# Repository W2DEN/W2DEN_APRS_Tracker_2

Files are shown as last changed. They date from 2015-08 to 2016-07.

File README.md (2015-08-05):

# W2DEN_APRS_Tracker_2
Tracker with a menu
This version will include a menu to allow users to change some of the 'default' data. A new version 'thread' was created so the original Tracker did not change. this will allow other development without the menu system included.
Who knows, where this is going!
UPDATE 8/5/15: For all practical purposes the software is complete. There will be some code refinements, the menu system is 'brute force' coding and needs some sophisitcation.
Documentaion will be brought up to speed on the N4SER.org site. 
NOTE: libraries included with the Arduino IDE and/or the Tensyduino IDE are NOT captured here. They will be documented as time allows.
73
Den

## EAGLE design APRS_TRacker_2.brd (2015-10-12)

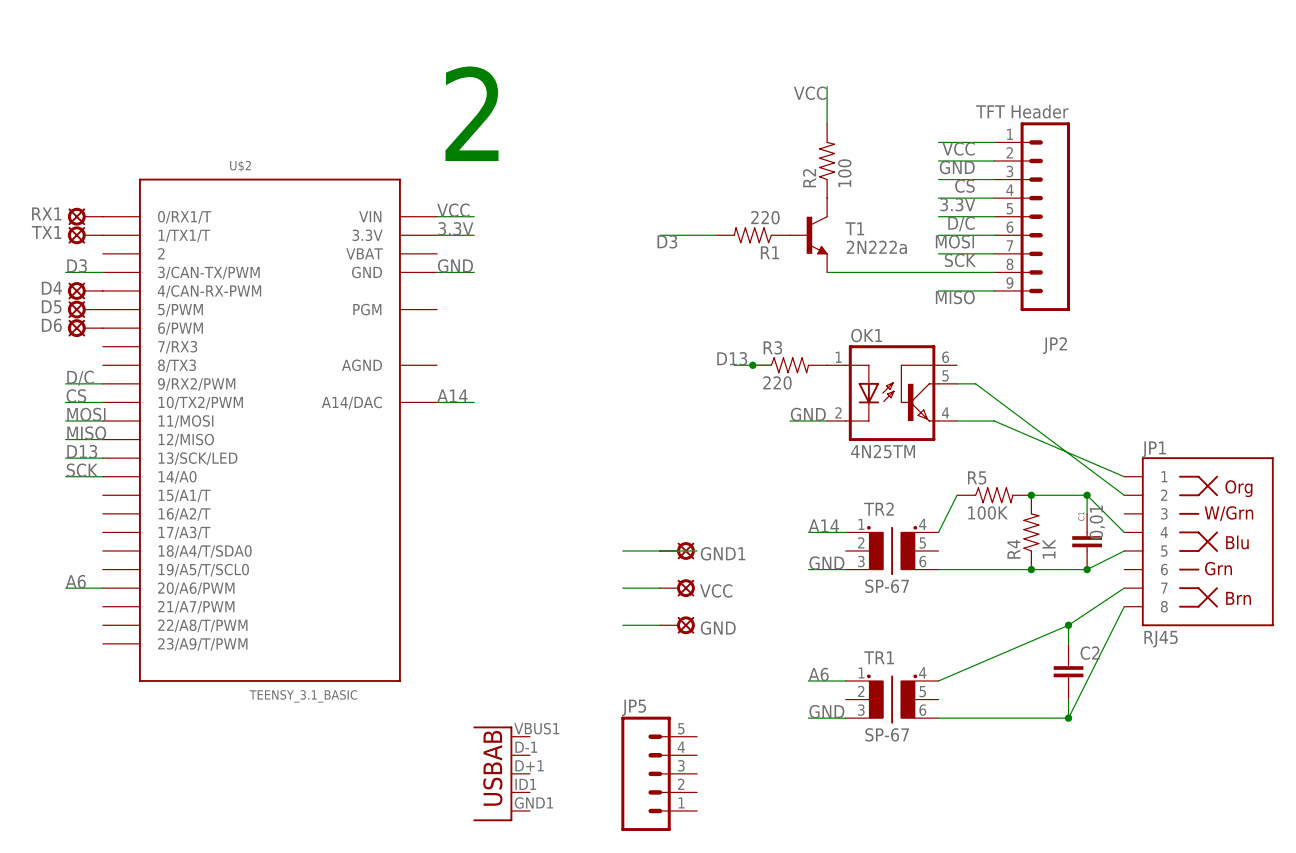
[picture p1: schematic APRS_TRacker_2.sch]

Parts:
C1: 0,01; CAP-PTH-SMALL2
C2: CAPPTH2; CAP-PTH-SMALL2
D4, D5, D6: LSP10
GND, GND1: LSP10
JP1: RJ45; RJ45-8
JP2: TFT Header; 1X09
JP5: M05PTH; 1X05
OK1: 4N25TM; DIL6-04
R1, R3: 220; AXIAL-0.4
R2: 100; AXIAL-0.4
R4: 1K; AXIAL-0.4
R5: 100K; AXIAL-0.4
RX1: LSP10
T1: 2N222a; TO-92
TR1, TR2: SP-67
TX1: LSP10
U$2: TEENSY_3.1_BASIC
U$4: USB-AB""; USB-AB-MICRO-SMD_V02_BOSS
VCC: LSP10

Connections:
3.3V: JP2.4, U$2.3.3V, U$2.3.3V1 (3.3V)
A6: TR1.1, U$2.20/A6 (20/A6/PWM)
A14: TR2.1, U$2.A14 (A14/DAC)
AGND: U$2.AGND
CS: JP2.3, U$2.10 (10/TX2/PWM)
D3: R1.P$2 (2), U$2.3 (3/CAN-TX/PWM)
D13: R3.P$1 (1), U$2.13 (13/SCK/LED)
D/C: JP2.5, U$2.9 (9/RX2/PWM)
GND: GND.MP, GND1.MP, JP2.2, OK1.2 (C), TR1.3, TR2.3, U$2.GND, U$2.GND1 (GND)
MISO: JP2.9, U$2.12 (12/MISO)
MOSI: JP2.6, U$2.11 (11/MOSI)
unnamed: R1.P$1 (1), T1.2 (B)
unnamed: R2.P$1 (1), T1.1 (C)
unnamed: OK1.1 (A), R3.P$2 (2)
unnamed: JP1.1, OK1.4 (EMI)
unnamed: JP1.2, OK1.5 (COL)
unnamed: C2.2, JP1.8, TR1.6
unnamed: C2.1, JP1.7, TR1.4
unnamed: C1.1, JP1.4, R4.P$2 (2), R5.P$2 (2)
unnamed: C1.2, JP1.5, R4.P$1 (1), TR2.6
unnamed: R5.P$1 (1), TR2.4
unnamed: D5.MP, U$2.5 (5/PWM)
unnamed: D6.MP, U$2.6 (6/PWM)
unnamed: D4.MP, U$2.4 (4/CAN-RX-PWM)
unnamed: RX1.MP, U$2.0 (0/RX1/T)
unnamed: TX1.MP, U$2.1 (1/TX1/T)
SCK: JP2.7, U$2.14/A0
T1: JP2.8, T1.3 (E)
VBAT: U$2.VBAT
VCC: JP2.1, R2.P$2 (2), U$2.VIN, VCC.MP

Board: 2 copper layers, 24 parts (1 on the bottom side), 28 nets, no tracks yet.

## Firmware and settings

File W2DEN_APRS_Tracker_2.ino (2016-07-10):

/*
* This is W2DEN's attempt at a Teensy3.1 APRS Tracker.
* This is V 2.03 adding a menu system to allow user input.
* see N4SER.org for details
* 
* Debugging: 
*   All serial.print lines have been remed out. //Serial.print. Un rem to use
*   Incuding the initiator line in Setup //Serial.begin(9600);
*
* Compiler Macro Substitutes (#define) in ALL_CAPS with underline for spaces
*
* The bases for this sketch comes from Richard Nash (KC3ARY). Without his code I'd still be searching
* Also thanks to:
*
    Ben Buxton: rotary encoder code ( http://www.buxtronix.net/2011/10/rotary-encoders-done-properly.html )
    9W2SVT: ASPRS Arduino with Display ( http://9w2svt.blogspot.com/ )
    M1GEO: APRS Blog ( http://www.george-smart.co.uk/wiki/APRS )
    KI4MCW: Balloonery ( https://sites.google.com/site/ki4mcw/ )
    BeRTOS Project ...
    Jinseok Jeon (JeonLab.wordpress.com): UTC calculator
    The APRS libraries come from the Trackduino project with modes by many before it got here.
Special mention goe to Jan Volschenk (ZS6VOL) who actuall built a W2DEN Tracker and helped me debug this code.
*
********************************************************************
*
*/
#define thisver "2.03" ////////////////////////////////// VERSION
// these define the starting EEPROM addresses.
// easier to change these than dig for the constants.
#define UTC_OFFSET 1
#define XMIT_TIME  2
#define MY_CALL    4
#define MY_SSID   10
#define DEST_CALL 11
#define DEST_SSID 17
#define SYM_TABLE 18
#define SYMBOL    19
#define COMMENT   20
#define SB_ENABLE    55 // these are SmartBeaconing eePROM addresses
#define SBFAST_SPEED 56
#define SBFAST_RATE  58
#define SBSLOW_SPEED 60
#define SBSLOW_RATE  62
#define SBTURN_TIME  64
#define SBTURN_ANGLE 66
#define SBTURN_SLOPE 68
#define AXDELAY      70
#define AXFLAGS      72
#define AXVOXON      74
#define AXVOXSILENT  76
#define PTT_PIN      78
#define TFT_ONOFF    80 // tft On / Off (1 / 0) EEPROM address only 1 byte
#define SQUELCH      81 // the squelch threshol eeprom address 

#define COMMLENGTH  35 // length of the AX.25 comment
#define NUM_SYMBOLS 10 // number of symbols in the symbols[] table

// includes
#include <WProgram.h>
#include <GPS.h>
#include <aprs.h>
#include <EEPROMex.h> // expanded EEPROM library

#include "SPI.h" // Set up the display
#include "ILI9341_t3.h"
ILI9341_t3 tft = ILI9341_t3(10, 9, 8, 11, 14, 12); //(CS,DC,RST,MOSI,SCLK,MISC)

static const int line = 25; //# of lines on screen @ font size 3

// rotary selector
#include <Bounce.h>
#define ROTARY_PIN1 5
#define ROTARY_PIN2 6
#define BUTTONPIN   4
#define DIR_CCW 0x10
#define DIR_CW 0x20
Bounce pushbutton = Bounce(BUTTONPIN, 10);
// Use the full-step state table (emits a code at 00 only)
const unsigned char ttable[7][4] = {
  {0x0, 0x2, 0x4,  0x0}, {0x3, 0x0, 0x1, 0x10},
  {0x3, 0x2, 0x0,  0x0}, {0x3, 0x2, 0x1,  0x0},
  {0x6, 0x0, 0x4,  0x0}, {0x6, 0x5, 0x0, 0x20},
  {0x6, 0x5, 0x4,  0x0},
};
volatile unsigned char state = 0;
void rotary_init() { // setas up the rotatry pins
  pinMode(ROTARY_PIN1, INPUT_PULLUP);
  pinMode(ROTARY_PIN2, INPUT_PULLUP);
  pinMode(BUTTONPIN, INPUT_PULLUP);
}
/* Read input pins and process for events. Call this either from a
 * loop or an interrupt (eg pin change or timer).
 * Returns 0 on no event, otherwise 0x80 or 0x40 depending on the direction.
 */
unsigned char rotary_process() {
  unsigned char pinstate = (digitalRead(ROTARY_PIN2) << 1) | digitalRead(ROTARY_PIN1);
  state = ttable[state & 0xf][pinstate];
  return (state & 0x30);
}
int DaysAMonth[] = { 31, 28, 31, 30, 31, 30, 31, 31, 30, 31, 30, 31};//number of days a month
int gpsYear;
int gpsMonth;
int gpsDay = 0;
int gpsHour;
#define knotToMPH 1.15078 // GPS speed is in knots... this is the conversion
////////////////////////////////////////////////////////////////////////////////

// Define the I/O pins
//#define PTT_PIN 13 // Push to talk pin tis is now eePROM
#define ROTARY_PIN1   5
#define ROTARY_PIN2   6
#define BUTTONPIN     4
#define TFT_ONOFF_PIN 3 // tft On Off PWM pin
#define SQUEL_PIN     A6       // these are constants for the squelch threshold
#define SQUEL_REF     INTERNAL
#define SQUEL_RES     10
#define SQUEL_AVE     16

////////////// user data set up //////////////////////////////
//
//this is all new. User data are read from EEPROM
//
// create the struct instance for the calls and paths//////////
//
struct PathAddress addresses[] = {
  {(char *)NULL, 0},  // Destination callsign
  {(char *)NULL, 0},  // Source callsign
  {(char *)NULL, 0},  // Digi1 (first digi in the chain)
  {(char *)NULL, 0}   // Digi2 (second digi in the chain)
};
//
// set up variables to hold EEPROM data //////////////////////
// make these global so we can edit them.
// variables are loaded to each xmit
//
int8_t TimeZone;    // utc offseti
uint16_t sTime;      // xmit delay if no smart beacon
char sCall[6];      // holds the s source call
char dCall[6];      // holds the d destination call
char buf;           // buffer for EEPROM read
char symTable;      // symbole table \ or //
char symbol;        // symbol > car etc/
char myComment[36]; // comments holder 35 chars + end
const char* symbols [][9] = { //table of symbols
  {"House", "/", "/"},
  {"Car", "/", ">"},
  {"M-Cycle", "/", "<"},
  {"Van", "/", "v"},
  {"Truck", "/", "k"},
  {"Bike", "/", "b"},
  {"Balloon", "/", "O"},
  {"SailBoat", "/", "y"},
  {"PwrBoat", "/", "s"},
  {"School", "/", "K"}
};
int8_t   sbEnable;       // use sb or not
uint16_t sbFastSpeed;    //mph speeds stored and compared as integers tostop oscilatting
uint16_t sbFastRate;     //seconds
uint16_t sbSlowSpeed;    // mph as integer
uint16_t sbSlowRate;
uint16_t sbMinTurnTime;  //sec
uint16_t sbMinTurnAngle; //degrees
uint16_t sbTurnSlope;    //
uint16_t axDelay;        // milliseconds
uint16_t axFlags;        // number of flags to send
uint16_t axVoxOn;        // mseconds vox tone sent to xmitter 0 for off
uint16_t axVoxSilent;    // mseconds VOX tone silent  0 for off
uint16_t pttPin;         // PTT Teensy Pin usually 13, 0 for off
int8_t   tftOnOff;       // tft brightness setting
uint16_t squelch;        // squelch threshold vlaue holder

uint16_t mySpeed   = 0;  // Holds gps.speed for processing
uint16_t myHeading = 0;
uint16_t sbSpeed   = 0;  //prior read speed
uint16_t sbHeading = 0;  // prior heading
//////////////////////// pre set up variables///////////////////////////
HardwareSerial &gpsSerial = Serial1;
GPS gps(&gpsSerial, true);
void mNumChoice(int eePromAddress, int8_t *variable, int lTZ, int uTZ,  int nTZ, String title, String help , uint16_t TTT = 0, uint16_t *variable2 = 0, bool e16bit = false );

uint32_t dTime;
uint32_t timeOfAPRS = 0;
bool gotGPS = false;

////////////////////////////////////////////////////////////////////////
////////////////////////////////////////////////////////// setup()
////////////////////////////////////////////////////////////////////////
void setup()
{
  //Serial.begin(9600); // For debugging output over the USB port
  // read the EEPROM user data into memory /// will be updated/////////
  /////////////////////////////////////////////////////////////////////
  TimeZone = EEPROM.read(UTC_OFFSET);
  // sTime is the start delay time sotred in eePROM as an int in seconds
  // dTime is the working xmit delay uint32_t starts as sTime then via SmartBeacon if activated.
  sTime = EEPROM.readInt(XMIT_TIME); // seconds
  dTime = sTime * 1000; // store the start time into dTime (delay) in milliseconds
  for (int i = MY_CALL; i < MY_CALL + 6; i++) { // Source call
    buf = EEPROM.read(i);
    if (buf == 32) break;
    sCall[i - MY_CALL] = buf;
  }
  for (int i = DEST_CALL; i < DEST_CALL + 6; i++) { //destinationn call
    buf = EEPROM.read(i);
    if (buf == 32) break;
    dCall[i - DEST_CALL] = buf;
  }

  for (int i = COMMENT; i < COMMENT + COMMLENGTH; i++) { // comment
    buf = EEPROM.read(i);
    myComment[i - COMMENT] = buf;
  }
  // now the SmartBeacon parameters...
  // 16 bit allows menu compatability
  sbEnable       = EEPROM.read(SB_ENABLE);
  sbFastSpeed    = EEPROM.readInt(SBFAST_SPEED); //mph speeds stored and compared as integers tostop oscilatting
  sbFastRate     = EEPROM.readInt(SBFAST_RATE);  //seconds
  sbSlowSpeed    = EEPROM.readInt(SBSLOW_SPEED); // mph as integer
  sbSlowRate     = EEPROM.readInt(SBSLOW_RATE);
  sbMinTurnTime  = EEPROM.readInt(SBTURN_TIME);  // sec
  sbMinTurnAngle = EEPROM.readInt(SBTURN_ANGLE); // degrees
  sbTurnSlope    = EEPROM.readInt(SBTURN_SLOPE); //
  axDelay        = EEPROM.readInt(AXDELAY);      // milliseconds
  axFlags        = EEPROM.readInt(AXFLAGS);      // number of flags to send
  axVoxOn        = EEPROM.readInt(AXVOXON );     // mseconds vox tone sent to xmitter 0 for off
  axVoxSilent    = EEPROM.readInt(AXVOXSILENT);  // mseconds VOX tone silent  0 for off
  pttPin         = EEPROM.readInt(PTT_PIN);      // PTT Teensy Pin usually 13, 0 for off
  tftOnOff       = EEPROM.read(TFT_ONOFF);       // tft On / Off: 1 or 0
  squelch        = EEPROM.readInt(SQUELCH);      // read ssquelch threshold from eePROM into variable
  /////////////////////////////////////////////////////////////////////////////////////////////////////
  tft.begin();
  pinMode(TFT_ONOFF_PIN, OUTPUT);
  digitalWrite(TFT_ONOFF_PIN, 1); /// this is the TFT display On Off set to on for boot
  tft.fillScreen(ILI9341_BLACK);
  tft.setRotation(2);
  tft.setCursor(0, 250);
  tft.setTextSize(2);
  if (tftOnOff) {
    tft.print("Display: On");
  }
  else {
    tft.print("Display: Off");
  }
  tft.setTextSize(3);
  tft.setTextColor(ILI9341_YELLOW, ILI9341_BLACK);
  tft.setCursor(0, 50);
  tft.println("W2DEN's");
  tft.println("APRS");
  tft.println("Tracker");
  tft.println("Loading ...");

  // start the GPS polling and wait for valid data... may take 15+ seconds
  gps.startSerial(9600);
  gps.setSentencesToReceive(OUTPUT_RMC_GGA);
  rotary_init(); // initialize the rotary
  // wait for a GPS sentence
  while (!(gps.sentenceAvailable())) {
    delay(1000);
  }

  gps.parseSentence();
  gps.dataRead();
  //   only proced if the dates are valid
  char rot[9] = {'|', '/', (char)195, '\\', '|', '/', (char)195, '\\'};
  uint i = 0;
  while (gps.month <= 0 || gps.day <= 0 || gps.year <= 0) { // || gps.speed > 0) {
    //Serial.print( gps.month);
    //Serial.print( "/");
    //Serial.print( gps.day);
    //Serial.print( "/");
    //Serial.println( gps.year);
    if (gps.sentenceAvailable()) gps.parseSentence();
    if (gps.newValuesSinceDataRead()) gps.dataRead();
    tft.setCursor(0, 150);
    tft.print(rot[i++]);
    if (i >= sizeof(rot) - 1) i = 0;
    delay(1000);
  }
  // Set up the APRS module
  aprs_setup(axFlags, // number of preamble flags (FLAG) (Hex: 0x7e, ASCII: ~, Binary: 01111110 )to send
             pttPin, // PTT Pin from eePROM
             axDelay, // ms to wait after PTT to transmit
             axVoxOn, axVoxSilent // VOX: tone length, silence length
            );

  // now data should be stable. Get set and enter the loop
  sbSpeed   = gps.speed;                //prior read speed
  sbHeading = gps.heading;
  myHeading = sbHeading;
  broadcastLocation(gps, myComment);
  timeOfAPRS = millis();
  digitalWrite(TFT_ONOFF_PIN, tftOnOff); /// this is the TFT display controller set to 255 on boot
  tft.fillScreen(ILI9341_BLACK);
  display();
  //eepromReader(); // for debugging: prints eeprom content t serial monitor 
  //Serial.printf("mPick: %i, mB4: %i\n\r", " mPick", " mB4");

}

////////////////////////////////////////////////////////////////////// loop()
void loop()
{
  // capture the button press
  if (pushbutton.update()) {
    //Serial.println("Button");
    if (pushbutton.fallingEdge()) {
      digitalWrite(TFT_ONOFF_PIN, 1); //Turn the screen on if it was off
      menu(addresses);
    }
  }

  // get GPS data
  if (gps.sentenceAvailable()) gps.parseSentence();
  if (gps.newValuesSinceDataRead()) {         // go here as the seconds tick
    displayCountDown();
    gps.dataRead();
    gotGPS = true; // prior validate idea... on the to do list
    if (sbEnable) {
      mySpeed   = round(gps.speed * knotToMPH); // convert knots to MPH and store.
      myHeading = round(gps.heading);           // store the heading
      // SmartBeacon... my way
      if ((sbSpeed != mySpeed)) {               // was speed changed?????
        //go if something changed
        if ((mySpeed > sbSlowSpeed) && (mySpeed < sbFastSpeed)) {
          dTime = (( ( float(sbFastSpeed) / float(mySpeed) ) * (sbFastRate)) * 1000); // - (millis() - timeOfAPRS);
        }
        if (mySpeed >= sbFastSpeed) {         // are we above the fast level
          dTime = (sbFastRate * 1000);        // - (millis() - timeOfAPRS);
        }
      }
      if (sbHeading != myHeading) {             // was heading changed?????????
        uint16_t sbTurnThreshold = sbMinTurnAngle + (sbTurnSlope / mySpeed); // smartbeacon formula
        //  do we send beacon for a direction change??
        int dif = sbHeading - myHeading;
        dif = abs(dif);
        if (abs(dif) > 180) {
          dif = dif - 360;
        }
        dif = abs(dif);
        if (dif > sbTurnThreshold) {                              //did we trun enough?
          if (((millis() - timeOfAPRS) / 1000) > sbMinTurnTime) { //did enough time pass?
            timeOfAPRS = millis() - dTime;        // set the tme so we xmit
            sbHeading = myHeading;
          }
          else {
            //Serial.println("not enuf time... reset");
            sbHeading = myHeading;              //not enough time so reset the heading and move on
          }
        }
      }
    }
    display();
    //Serial.printf("Sec: %d Heading %d Knots: %f\n\r", gps.seconds, gps.heading, gps.speed);
    //Serial.printf("Location: %f, %f Heading %d Knots: %f\n\r", gps.latitude, gps.longitude,gps.heading, gps.speed);
    //Serial.printf("dTime %i timeOf %i dT+timeOf %i millis %i\n\r", dTime, timeOfAPRS, dTime + timeOfAPRS, millis());
    //Serial.print((millis() - timeOfAPRS) / 1000);
  }
  // do we xmit?
  if (gotGPS && timeOfAPRS + dTime < millis()) {
    broadcastLocation(gps, myComment );
    timeOfAPRS = millis(); // reset the timer
    //Serial.printf("dTime: %d gps.speed: %f sbSpeed %f sbSlowrate: %d\n\r", dTime, gps.speed, sbSpeed , sbSlowRate);
    // SmartBeacon speed < low speed test and adjust as needed.
    if (sbEnable) {
      sbHeading = gps.heading; // reset the heading milestone.
      sbSpeed = gps.speed * knotToMPH; //store the new speed.
      if (gps.speed < sbSlowSpeed && sbSpeed < sbSlowSpeed && dTime < (sbSlowRate * 1000) ) {
        dTime = 2 * dTime;
        if (dTime > (sbSlowRate * 1000) ) dTime = sbSlowRate * 1000;
      }
    }
    display();
  }
} // Loop end YES the main loop ends here...


/////////////////////////////////////////////////////////////////////////////
//                                                                         //
//       FUNCTIONS from here down                                          //
//                                                                         //
/////////////////////////////////////////////////////////////////////////////

////////////////////////////////////////////////////////////// eepromReader()
// for debugging prints eeprom content to serial monitor
void eepromReader() {
  unsigned int address = 0;
  byte value;
  Serial.print("EEPROM Content");
  Serial.println();
  while (address < 100) {
    // read a byte from the current address of the EEPROM
    value = EEPROM.read(address);

    Serial.print(address);
    Serial.print("\t");
    Serial.print(value, DEC);
    if (value > 30 and value < 240) {
      Serial.print("\t");
      Serial.print(char(value));
    }
    Serial.println();
    address = address + 1;
  }
}

/////////////////////////////////////////////////////////////////////// squelcher()
// returns the integer value on the SQUEL_PIN
int squelcher() {
  // read the audio level 10 times at 10 millisecond inetervals (100 msec )
  // return the total
  analogReference(SQUEL_REF );
  analogReadResolution(SQUEL_RES);
  analogReadAveraging(SQUEL_AVE);
  int t = 0;
  for (int i = 0; i < 10; i++) {
    t = t + analogRead(SQUEL_PIN);
    delay (10);
  }
  return t;
}


/////////////////////////////////////////////////////////////////////// menuHeader()
// draws the menus
//
void menuHeader(String title, int mStart, int mEnd, int mPick, String menu1[][2]  ) {
  tft.fillScreen(ILI9341_BLUE);
  tft.setTextSize(3);
  tft.setTextColor(ILI9341_WHITE, ILI9341_BLUE);
  tft.setCursor(0, 0);
  tft.println(title);
  for (int i = mStart; i <= mEnd; i++) {
    tft.setCursor(0, (i + 1) * 25);
    if (i == mPick) {
      tft.setTextColor(ILI9341_BLUE, ILI9341_WHITE);
    }
    else
    {
      tft.setTextColor(ILI9341_WHITE, ILI9341_BLUE);
    }
    //tft.print(String(i) + " ");
    tft.print(menu1[i][0] + menu1[i][1]);
  }
}


/////////////////////////////////////////////////////////////////////// menu()
void menu(const PathAddress *  paths) {
  {
    // lets set it up
    int mStart = 0;   //First menu item
    int mEnd   = 5;   // last menu item
    int mPick  = 0;   // menu choice
    int mB4    = 0;   // line # befor move
    String onOff;
    if (tftOnOff) {
      onOff = "On";
    }
    else {
      onOff = "Off";
    }
    //String displayOnOff = "Display:" + onOff;
    //this defines the menu
    String menu1[][2] = {
      {"Return", ""},
      {"Send/Return", ""},
      {"Packet", ""},
      {"AX.25", ""},
      {"SmartBeacon", ""},
      {"Display: " , onOff}
    } ;
    //now draw it
    menuHeader("Main  Menu", mStart, mEnd, mPick, menu1  );
    // now loop looking for a rotation or a button press
    while (true)
    {
      unsigned char result = rotary_process(); // rotated?
      if (result) {                            // the button was rotated
        if (result == DIR_CCW) {               // highlight the next choice
          if (--mPick < mStart) mPick = mEnd;
        }
        else {
          if (++mPick > mEnd) mPick = mStart;
        }
        Serial.printf("mPick: %i, mB4: %i\n\r", mPick, mB4);
        tft.setCursor(0, (mB4 + 1) * 25);
        tft.setTextColor(ILI9341_WHITE, ILI9341_BLUE);
        tft.print(menu1[mB4][0] + menu1[mB4][1]);
        tft.setCursor(0, (mPick + 1) * 25);
        tft.setTextColor(ILI9341_BLUE, ILI9341_WHITE);
        tft.print(menu1[mPick][0] + menu1[mPick][1]);
        tft.setTextColor(ILI9341_WHITE, ILI9341_BLUE);
        mB4 = mPick;
      }
      if (pushbutton.update()) {                // button pushed
        if (pushbutton.fallingEdge()) {
          switch (mPick) {                      //handle the button push
            case 0:  // return
              tft.fillScreen(ILI9341_BLACK);
              display();
              digitalWrite(TFT_ONOFF_PIN, tftOnOff); // reset the display
              return;
            case 1:  // send and return
              gps.dataRead();
              broadcastLocation(gps, myComment );
              tft.fillScreen(ILI9341_BLACK);
              timeOfAPRS = millis();
              display();
              digitalWrite(TFT_ONOFF_PIN, tftOnOff); // reset the display
              return;
            case 2: // sendMenu
              packetMenu(paths);
              menuHeader("Main  Menu", mStart, mEnd, 2, menu1  );
              break;
            case 3: // sendMenu
              ax25Menu();
              menuHeader("Main  Menu", mStart, mEnd, 3, menu1  );
              break;
            case 4: // SmartBeacon Menu
              sbMenu();
              menuHeader("Main  Menu", mStart, mEnd, 4, menu1  );
              break;
            case 5: // Display On or Off
              mNumChoice(TFT_ONOFF, &tftOnOff , 0, 1, tftOnOff , String("Display On / Off"), "1 = On              0 = Off");
              if (tftOnOff) {
                onOff = "On";
              }
              else {
                onOff = "Off";
              }
              menu1[5][1] = onOff;
              menuHeader("Main Menu", mStart, mEnd, 5, menu1  );
              break;
          } // switch end
        }   // if (pushbutton.update())
      }     // if (pushbutton.fallingEdge())
    }       // while (true) end
  }         // end of menu function
}
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

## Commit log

2015-07-06 Tracker with a menu
    Added the Push Button and Rotary Encoder code. Nothin in the menu yet.
2015-07-30 Smart Beacon and Screen Update,
    Improvements to the stability of the Smart Beacon.
    Screen updated to clean it up and stop the flashing on update.
    The SB may need a % update as speed changes... this will be
    investigated.
    [W2DEN_APRS_Tracker_2.ino]
2015-08-05 Menu complete
    The two level, 4 'page' menu is now complete. This allows user control
    of all APRS parameters. Well, any you'd want to change. The AX.25 page
    has not been fully tested due to a human induced hardware failure. next
    steps: update the software documentation on the N4SER.org site, code
    cleanup, and a smaller box.
    73 W2DEN
    [W2DEN_APRS_Tracker_2.ino]
2015-08-25 Version 2.02 debugged and ready
    Some debugging... fixed transmit time now working correctly. Added
    squelch detect (audio monitoring) to help avoid collisions.
    [W2DEN_APRS_Tracker_2.ino]
2015-10-12 Eagle Tracker 2 Board
    This Eagle board is only airwires. Can be routed if you want to print
    it.
    [APRS_TRacker_2.brd, APRS_TRacker_2.sch]
2016-05-05 Debug
    Corrected sub-menu rotation issues.
    [W2DEN_APRS_Tracker_2.ino]
2016-07-10 DeBug Call sign error
    Thanks to Jan (VS6VOL) who has built a W2DEN Tracker for hi great input
    on debugging a call sign length bug.
    [W2DEN_APRS_Tracker_2.ino]

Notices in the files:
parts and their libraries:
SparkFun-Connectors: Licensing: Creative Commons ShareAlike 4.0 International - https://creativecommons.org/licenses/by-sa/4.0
